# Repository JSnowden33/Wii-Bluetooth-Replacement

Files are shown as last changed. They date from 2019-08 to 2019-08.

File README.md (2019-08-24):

# Wii Bluetooth Replacement

<p align="center">
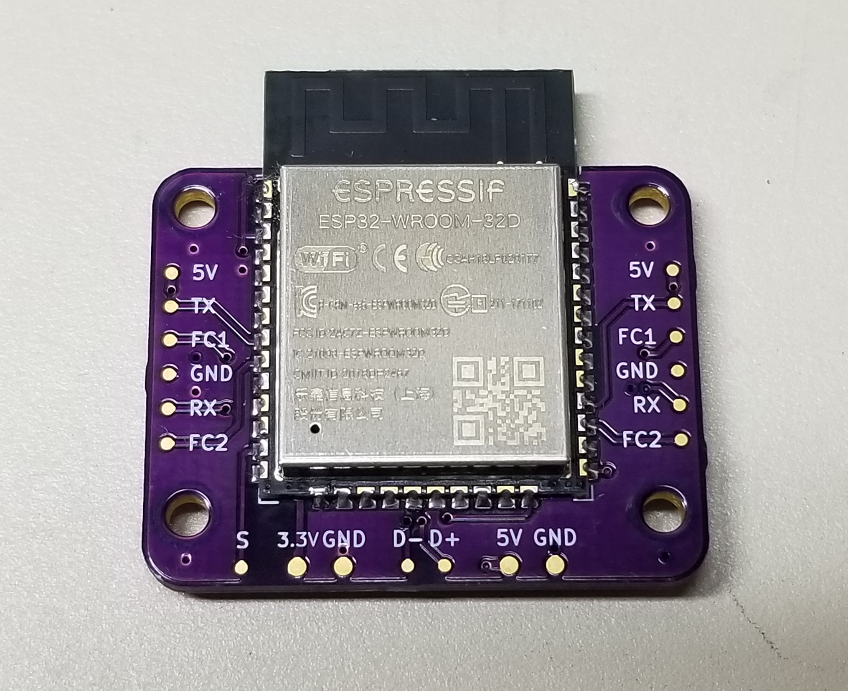
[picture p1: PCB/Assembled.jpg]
ESP32 Wii Bluetooth Replacement
  
</p>

This project is a full replacement for the Nintendo Wii's Bluetooth module. Emulation of the Bluetooth module is performed on the PIC32 based on [rnconrad's emulator](https://github.com/rnconrad/WiiBluetoothEmulator), while controller connectivity on the ESP32 is based on [btstack](https://github.com/bluekitchen/btstack).

The device interfaces with various wireless controllers and emulates up to 4 virtual Wii Remotes to communicate with the Wii. Virtual Wii Remotes can be configured to have a Nunchuk, Classic Controller, or neither. Currently supported controllers are Wii Remote, Wii U Pro Controller, Joy-Con, and Switch Pro Controller. Joy-Con can also be used through wired functionality.

The PCB for this design can be purchased [here](https://oshpark.com/shared_projects/co8uBM0Z).

## Usage

The board needs to be powered by 3.3V. The only connection needed to the Wii are the D+ and D- USB lines, which should be wired where the Bluetooth module normally sits. The 5V input is only used for Joy-Con charging and not needed to use the Joy-Con. The "S" pin is for the sync button, which can be a normally open tact switch connected to GND.

## Supported Features

- Permanent syncing: Press the sync button on the ESP32 along with the sync button on any controllers you want to pair. The ESP32 will pair and store each controller's information so reconnection works smoothly. Joy-Con can also be paired by docking them to the ESP32.

- Extension switching: Controllers that don't support physical extensions (Nunchuk and Classic Controller) can cycle through virtual extensions. Long-press Home to cycle through each one. Switch and Wii U Pro Controllers support sideways Wii Remote, Nunchuk, and Classic Controller. Dual Joy-Con support Nunchuk and Classic Controller. Single Joy-Con (R) supports only vertical Wii Remote and Joy-Con (L) supports only Nunchuk.

- IR pointer emulation: The Wii Remote IR pointer is emulated by gyro control (for Joy-Con, Switch Pro, and Wii Remote Plus) or by the right joystick for any controllers that have it. The cursor can be re-centered by pressing R (long-press Plus on Wii Remote). Gyro can be re-calibrated by long-pressing R (long-press Home on Wii Remote) and letting the controller be still for a few seconds.

## Planned Features

- New platform: A hardware revision is planned based on the PIC32MX470F512 and the TI CC2564 BT module. This will hopefully resolve some current hardware issues and improve data throughput with more processing speed.

- DPad to joystick mapping: The Wii Remote DPad will eventually be mapped to the left joystick whenever a controller has no virtual extension attached.

- More single Joy-Con functionality: Each single Joy-Con (L or R) will eventually be usable as its own Wii Remote. Single Joy-Con mode will be enabled by holding SL + SR for a few seconds after the Joy-Con is connected. Each will function as a sideways Wii Remote with full motion control and a gyro pointer which can be toggled by pressing the joystick.

- More wired Joy-Con functionality: Wired Joy-Con are not well tested and implementation is unfinished. They currently do not support virtual extensions or rumble. 

- Wii Motion Plus: Motion Plus emulation is mostly implemented but not tested. It should be functional on any controller with a gyroscope.

## Known Issues

This project is experimental and has plenty of bugs. Below is a list of some important issues that still need fixing.

- Wii Remote connectivity: Currently only newer Wii Remotes (TR versions) can auto-connect to the ESP32 by pressing any button on the controller. Older Wii Remotes must be synced every time. This is due to a hardware incompatibility with the ESP32 and fixing it will require moving away from the ESP32 platform.

- Joy-Con connectivity: Joy-Con are finnicky and sometimes won't auto-connect. Fixing this will also require moving away from the ESP32 platform (but this issue seems to exist on some other platforms too). Resetting the Joy-Con by pressing the black button on the side seems to help.

- Reconnecting a controller: The PIC32 currently doesn't handle reconnections very well and may become unusable in-game if you disconnect a controller and try to reconnect it. Power cycling may be necessary (pressing the reset button on the Wii doesn't reinitialize the Bluetooth module).

- Multiplayer use: Connecting more players beyond player 1 may not work well or at all depending on the software. Using two Joy-Con for the same player works fine.

- HD rumble: Joy-Con and Switch Pro Controllers do support rumble and it usually works fine, but sometimes it will stop working until the controller is reconnected. Needs to be looked into.

## Joy-Con Wiring

The Joy-Con wired connection follows the pin numbering provided [here](https://github.com/dekuNukem/Nintendo_Switch_Reverse_Engineering). On each Joy-Con, the pin names vs. pin numbers are as follows:

- 5V: Pin 4
- TX: Pin 5
- FC1: Pin 6
- GND: Pin 7
- RX: Pin 8
- FC2: Pin 10

If a Joy-Con rail connector is wired to the board, pins 1, 2, 3, and 7 on the rail should be grounded. Pin 9 should be left unconnected. Connecting 5V to pin 4 for charging is optional. Note that having 5V active on the rail at all times may be unsafe if the connection isn't tight. 
When assembling the board, components U1, U2, C3, C4, and C6 are used only for Joy-Con connectivity and can be left off if wired Joy-Con will not be used.

## Compiling and Programming

### PIC32

Compiling the PIC32 software requires MPLAB X IDE with XC32 installed. Simply open the .X folder under Software/PIC32 as an MPLAB project and compile. The compiled image can be flashed using a PICKit3 connected to the MCLR, PGD, and PGC pins on the underside of the board. The board will need to be powered externally and the PICKit3 will need to be connected to 3.3V and GND references.

### ESP32

Compiling the ESP32 software requires installing both esp-idf and btstack. On Windows 10, I use the Msys32 terminal for esp-idf. Btstack can be downloaded from [here](https://github.com/bluekitchen/btstack). The port/esp32/integrate_btstack.py script will install btstack to your system after esp-idf has been installed. The software can be flashed to the ESP32 using any USB-serial programmer that has the appropriate transistors on the DTS and RTS lines. Those transistors should be connected to the EN and BOOT pins on the underside of the board (RX and TX go to the communication pins of the serial port). Running "make flash" in the Msys32 terminal will compile and flash the software to your board. The first compilation will take a VERY long time.

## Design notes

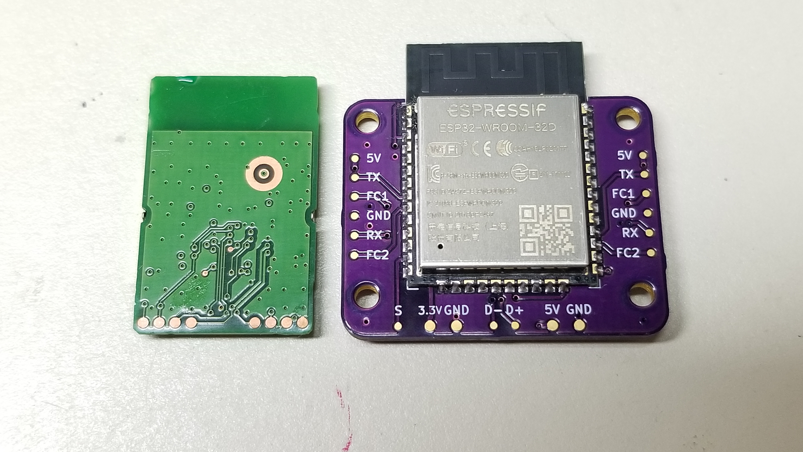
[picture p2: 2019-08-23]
PCB/Original vs Replacement.jpg

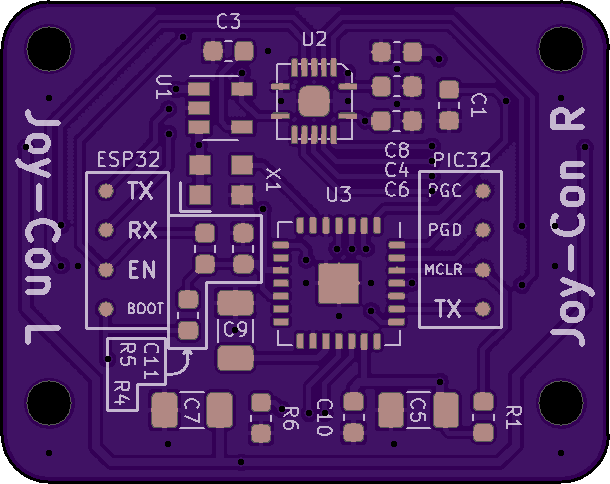
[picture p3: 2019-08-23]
PCB/Back.png

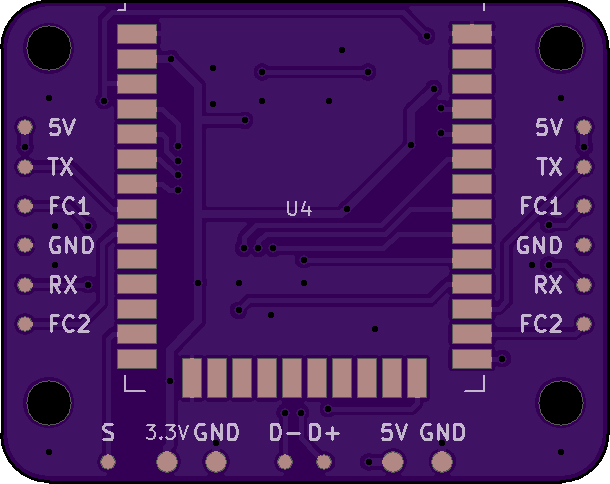
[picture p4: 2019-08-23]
PCB/Front.png

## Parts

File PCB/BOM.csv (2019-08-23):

Qty | Description | Value | Link
1 | SMD Capacitor 0603 | 1nF | Any - should be at least 6.3V tolerant
1 | SMD Capacitor 0603 | 22nF | Any - should be at least 6.3V tolerant
2 | SMD Capacitor 0603 | 0.1uF | Any - should be at least 6.3V tolerant
3 | SMD Capacitor 0603 | 1uF | Any - should be at least 6.3V tolerant
3 | SMD Capacitor 1206 | 10uF | Any - should be at least 6.3V tolerant
3 | SMD Resistor 0603 | 5kOhm | Any
1 | SMD Resistor 0603 | 12kOhm | Any
1 | 1.8V Linear Regulator | RT9193-18GB | https://www.digikey.com/product-detail/en/richtek-usa-inc/RT9193-18GB/1028-1016-1-ND/2470075
1 | Logic Level Translator | TXS0104ERGYR | https://www.digikey.com/product-detail/en/texas-instruments/TXS0104ERGYR/296-20698-1-ND/1143682
1 | PIC32 Microcontroller | PIC32MX270F256B-50I/ML | https://www.digikey.com/product-detail/en/microchip-technology/PIC32MX270F256B-50I-ML/PIC32MX270F256B-50I-ML-ND/4902624
1 | ESP32 Microcontroller | ESP32-WROOM-32D | https://www.digikey.com/product-detail/en/espressif-systems/ESP32-WROOM-32D/1904-1023-1-ND/9381732
1 | 8MHz Oscillator | ASEM1-8.000MHZ-LC-T | https://www.digikey.com/product-detail/en/abracon-llc/ASEM1-8.000MHZ-LC-T/535-9754-1-ND/1873288

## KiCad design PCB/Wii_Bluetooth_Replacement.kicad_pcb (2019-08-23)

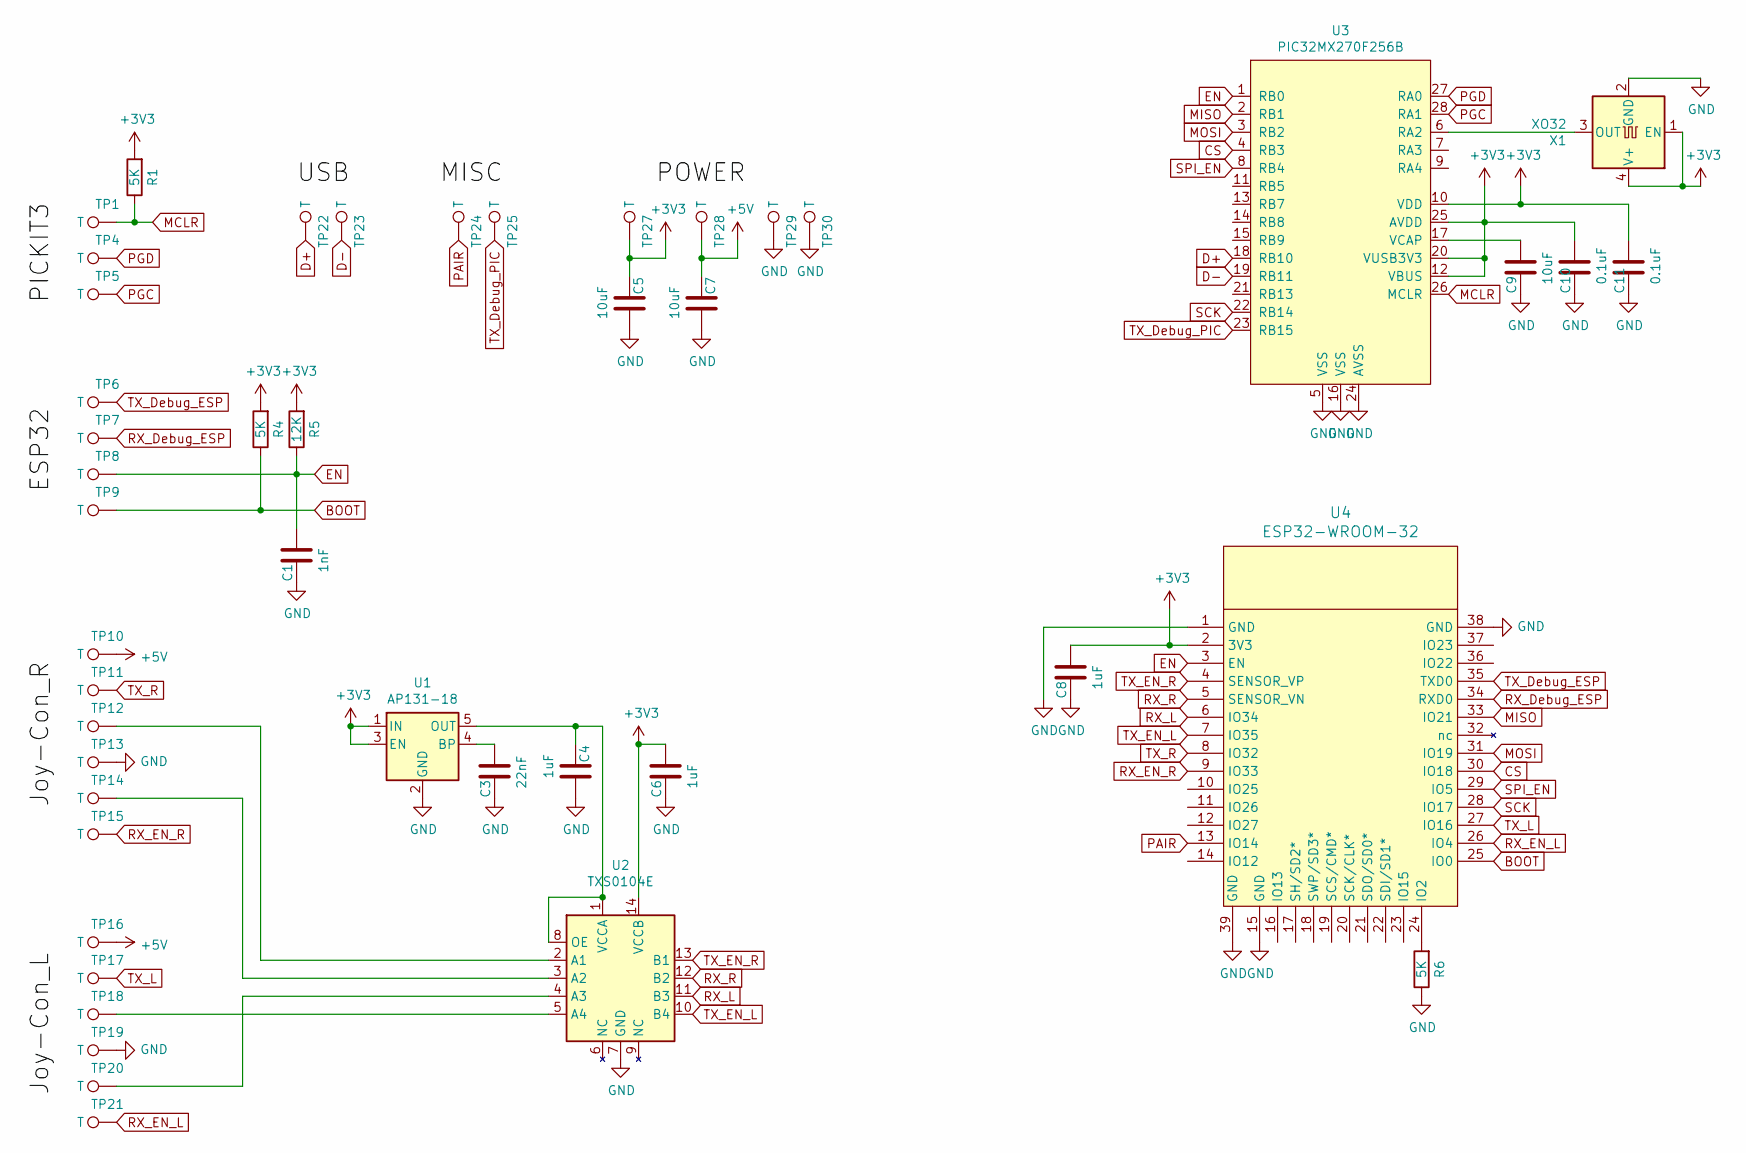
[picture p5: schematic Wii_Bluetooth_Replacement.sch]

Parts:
C1: 1nF; C_0603_1608Metric
C3: 22nF; C_0603_1608Metric
C4, C6, C8: 1uF; C_0603_1608Metric
C5, C7, C9: 10uF; C_1206_3216Metric
C10, C11: 0.1uF; C_0603_1608Metric
R1, R4, R6: 5K; R_0603_1608Metric
R5: 12K; R_0603_1608Metric
TP1, TP4, TP5, TP6, TP7, TP8, TP9, TP10, TP11, TP12, TP13, TP14, TP15, TP16, TP17, TP18, TP19, TP20, TP21, TP22, TP23, TP24, TP25: T; TestPoint_Pad_D0.7mm_NoSilk
TP27, TP28, TP29, TP30: T; TestPoint_Pad_D1.0mm_NoSilk
U1: AP131-18; SOT-23-5
U2: TXS0104E; VQFN-14_3.5x3.5mm_P0.5mm
U3: PIC32MX270F256B; QFN-28-1EP_6x6mm_P0.65mm_EP2.5x2.5mm
U4: ESP32-WROOM-32
X1: XO32; Oscillator_SMD_EuroQuartz_XO32-4Pin_3.2x2.5mm

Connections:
+3V3: C5.2, C6.1, C8.1, C10.1, C11.1, R1.2, R4.2, R5.2, TP27.1, U1.1 (IN), U1.3 (EN), U2.14 (VCCB), U3.10 (VDD), U3.12 (VBUS), U3.20 (VUSB3V3), U3.25 (AVDD), U4.2 (3V3), X1.1 (EN), X1.4 (V+)
+5V: C7.2, TP10.1, TP16.1, TP28.1
BOOT: R4.1, TP9.1, U4.25 (IO0)
CS: U3.4 (RB3), U4.30 (IO18)
D+: TP22.1, U3.18 (RB10)
D-: TP23.1, U3.19 (RB11)
EN: C1.1, R5.1, TP8.1, U3.1 (RB0), U4.3 (EN)
GND: C1.2, C3.2, C4.1, C5.1, C6.2, C7.1, C8.2, C9.2, C10.2, C11.2, R6.1, TP13.1, TP19.1, TP29.1, TP30.1, U1.2 (GND), U2.7 (GND), U2.15, U3.5 (VSS), U3.16 (VSS), U3.24 (AVSS), U3.29, U4.1 (GND), U4.15 (GND), U4.38 (GND), U4.39 (GND), X1.2 (GND)
MCLR: R1.1, TP1.1, U3.26 (MCLR)
MISO: U3.2 (RB1), U4.33 (IO21)
MOSI: U3.3 (RB2), U4.31 (IO19)
unnamed: C3.1, U1.4 (BP)
unnamed: C4.2, U1.5 (OUT), U2.1 (VCCA), U2.8 (OE)
unnamed: C9.1, U3.17 (VCAP)
unnamed: R6.2, U4.24 (IO2)
unnamed: TP12.1, U2.2 (A1)
unnamed: TP14.1, U2.3 (A2)
unnamed: TP18.1, U2.5 (A4)
unnamed: TP20.1, U2.4 (A3)
unnamed: U3.6 (RA2), X1.3 (OUT)
PAIR: TP24.1, U4.13 (IO14)
PGC: TP5.1, U3.28 (RA1)
PGD: TP4.1, U3.27 (RA0)
RX_Debug_ESP: TP7.1, U4.34 (RXD0)
RX_EN_L: TP21.1, U4.26 (IO4)
RX_EN_R: TP15.1, U4.9 (IO33)
RX_L: U2.11 (B3), U4.6 (IO34)
RX_R: U2.12 (B2), U4.5 (SENSOR_VN)
SCK: U3.22 (RB14), U4.28 (IO17)
SPI_EN: U3.8 (RB4), U4.29 (IO5)
TX_Debug_ESP: TP6.1, U4.35 (TXD0)
TX_Debug_PIC: TP25.1, U3.23 (RB15)
TX_EN_L: U2.10 (B4), U4.7 (IO35)
TX_EN_R: U2.13 (B1), U4.4 (SENSOR_VP)
TX_L: TP17.1, U4.27 (IO16)
TX_R: TP11.1, U4.8 (IO32)

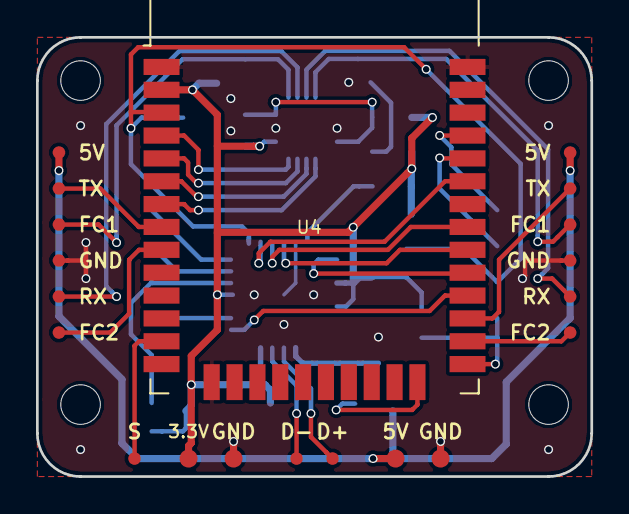
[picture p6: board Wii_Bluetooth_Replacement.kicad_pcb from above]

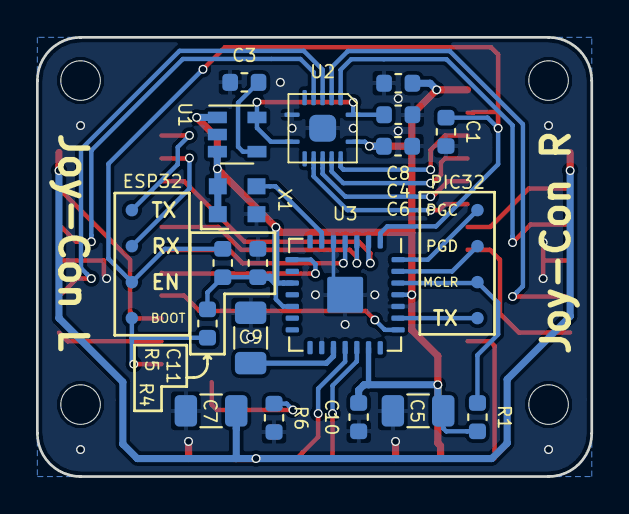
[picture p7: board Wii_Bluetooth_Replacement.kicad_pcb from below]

Board: 2 copper layers, 30.8 x 24.4 mm, 46 parts (26 on the bottom side), 36 nets.

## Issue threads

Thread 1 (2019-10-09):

Wii Remote connectivity on older Wii Remotes

gustavodinis, 2019-10-09:
Hello,
With regard to this known issue:
Wii Remote connectivity: Currently only newer Wii Remotes (TR versions) can auto-connect to the ESP32 by pressing any button on the controller. Older Wii Remotes must be synced every time. This is due to a hardware incompatibility with the ESP32 and fixing it will require moving away from the ESP32 platform.

Can you please provide any insights of what the problem is? I'm trying to figure out a solution. I don't have a Bluetooth sniffer but I'm assuming that is some issue with the BTstack of ESP32.

Thank you in advance and apologies for opening an issue (only way for me to get in touch with your work)

JSnowden33, 2019-10-09:
Hi,

There isn't much info on the issue except what is mentioned here: https://groups.google.com/forum/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

The original Wiimote can be synced to the ESP32, but reconnection fails. The Wiimote basically does not see the ESP32's request for role switch during reconnection. It seems as if the Wiimote does not see the commands exactly as they are sent from BTstack, so it may be some hardware issue in the physical link between the ESP32 and the Wiimote. It's hard to say how this could be debugged without a Bluetooth sniffer.

nathanRamaNoodles, 2020-01-09:
If we get a Bluetooth sniffer won't the data still be encrypted since its Bluetooth Classic?  I was reading an [issue in Ubertooth's repo](https://github.com/greatscottgadgets/ubertooth/issues/302#issuecomment-373445950) and their sniffer can't decrypt the Wii's Bluetooth packets.

Is there another sniffer that would work to sniff BT Classic?

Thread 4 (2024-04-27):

Reverse

pknessness, 2024-04-27:
Are there resources I could use to attempt to do this in the opposite way? I would like to have an ESP32 pretend to be a wii remote and connect to my wii.

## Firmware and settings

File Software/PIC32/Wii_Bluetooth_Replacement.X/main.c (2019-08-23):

#include <stdint.h>
#include <stdbool.h>
#include <stdlib.h>
#include "usb.h"
#include "hci.h"
#include <xc.h>
#include <string.h>
#include "usb_config.h"
#include "usb_ch9.h"
#include "usb_hid.h"
#include "uart.h"
#include "delay.h"
#include "wiimote.h"

// DEVCFG3
#pragma config PMDL1WAY = OFF           // Peripheral Module Disable Configuration (Allow only one reconfiguration)
#pragma config IOL1WAY = OFF            // Peripheral Pin Select Configuration (Allow only one reconfiguration)
#pragma config FUSBIDIO = ON            // USB USID Selection (Controlled by the USB Module)
#pragma config FVBUSONIO = OFF          // USB VBUS ON Selection (Controlled by software)

// DEVCFG2
#pragma config FPLLIDIV = DIV_2         // PLL Input Divider (2x Divider)
#pragma config FPLLMUL = MUL_15         // PLL Multiplier (15x Multiplier)
#pragma config UPLLIDIV = DIV_2         // USB PLL Input Divider (2x Divider)
#pragma config UPLLEN = ON              // USB PLL Enable (Enabled)
//#pragma config FPLLODIV = DIV_2         // System PLL Output Clock Divider (PLL Divide by 2) (30 MHz)
#pragma config FPLLODIV = DIV_1         // System PLL Output Clock Divider (PLL Divide by 1) (60 MHz, overclocked)

// DEVCFG1
#pragma config FNOSC = PRIPLL           // Oscillator Selection Bits (Primary Osc w/PLL (XT+,HS+,EC+PLL))
#pragma config FSOSCEN = OFF            // Secondary Oscillator Enable (Disabled)
#pragma config IESO = OFF               // Internal/External Switch Over (Disabled)
#pragma config POSCMOD = HS             // Primary Oscillator Configuration (HS osc mode)
#pragma config OSCIOFNC = OFF           // CLKO Output Signal Active on the OSCO Pin (Disabled)
#pragma config FPBDIV = DIV_4           // Peripheral Clock Divisor (Pb_Clk is Sys_Clk/4)
#pragma config FCKSM = CSDCMD           // Clock Switching and Monitor Selection (Clock Switch Disable, FSCM Disabled)
#pragma config WDTPS = PS1              // Watchdog Timer Postscaler (1:1)
#pragma config WINDIS = OFF             // Watchdog Timer Window Enable (Watchdog Timer is in Non-Window Mode)
#pragma config FWDTEN = OFF             // Watchdog Timer Enable (WDT Disabled (SWDTEN Bit Controls))
#pragma config FWDTWINSZ = WINSZ_25     // Watchdog Timer Window Size (Window Size is 25%)

// DEVCFG0
#pragma config JTAGEN = OFF             // JTAG Enable (JTAG Port Enabled)
#pragma config ICESEL = ICS_PGx1        // ICE/ICD Comm Channel Select (Communicate on PGEC1/PGED1)
#pragma config PWP = OFF                // Program Flash Write Protect (Disable)
#pragma config BWP = OFF                // Boot Flash Write Protect bit (Protection Disabled)
#pragma config CP = OFF                 // Code Protect (Protection Disabled)

static int32_t hci_len = 0;
static uint32_t hci_reset_timer = 0;

static uint32_t _excep_code;
static uint32_t _excep_addr;
// This function overrides the normal weak generic handler
void _general_exception_handler(void) {
	asm volatile("mfc0 %0,$13" : "=r" (_excep_code));
	asm volatile("mfc0 %0,$14" : "=r" (_excep_addr));
	_excep_code = (_excep_code & 0x0000007C) >> 2;    

	uart_transmit("Exception value/address:", 1);
	uart_transmit_val(_excep_code, 8, 1);
	uart_transmit_val(_excep_addr, 8, 1);

	while (1);
}

void __attribute__((vector(_TIMER_3_VECTOR), interrupt(), nomips16)) _T3Interrupt() {
	main_timer++;	// Count ms
	IFS0bits.T3IF = 0;
}

int main(void) {
	TRISBbits.TRISB0 = 0;	// ESP32 EN
	TRISBbits.TRISB1 = 1;	// SDI
	TRISBbits.TRISB2 = 0;   // SDO
	TRISBbits.TRISB3 = 0;   // CS
	TRISBbits.TRISB4 = 1;   // SPI_EN
	TRISBbits.TRISB14 = 0;  // SCK
	TRISBbits.TRISB15 = 0;  // TX
	
	LATBbits.LATB0 = 0;

	// Set all pins as digital
	ANSELA = 0;
	ANSELB = 0;

	// Allow multi-vector interrupts for USB
	INTCONbits.MVEC = 1;
	IPC7bits.USBIP = 4;
	__asm volatile("ei");

	t2_count_ms();
	uart_configure(115200);
	spi_master_init(2000000, 1);
	uart_transmit("UART init", 1);

	if (RCONbits.SWR) uart_transmit("RST - software", 1);
	if (RCONbits.WDTO) uart_transmit("RST - watchdog", 1);
	if (RCONbits.SLEEP) uart_transmit("RST - wakeup", 1);
	if (RCONbits.IDLE) uart_transmit("RST - was idle", 1);
	if (RCONbits.BOR) uart_transmit("RST - brown-out", 1);
	if (RCONbits.POR) uart_transmit("RST - power-on", 1);
	RCON = 0;

	usb_init();
	
	LATBbits.LATB0 = 1;
	TRISBbits.TRISB0 = 1;

	while (1) {
		if (usb_is_configured()) {
			if (!usb_in_endpoint_busy(1)) {
				int32_t len = hci_get_event(usb_get_in_buffer(1));
				if (len > 0) usb_send_in_buffer(1, len);
			}
			if (!usb_in_endpoint_busy(2)) {
				int32_t len = hci_get_data(usb_get_in_buffer(2));
				if (len > 0) usb_send_in_buffer(2, len);
			}
		}
		
		update_wiimotes();
		
		// Handle ESP32 reset
		/*
		if (hci_reset_status) {
			hci_reset_timer = main_timer;
			hci_reset_status = 0;
			TRISBbits.TRISB0 = 0;
			LATBbits.LATB0 = 0;
		}
		if ((main_timer - hci_reset_timer >= 50) && !PORTBbits.RB0) {
			LATBbits.LATB0 = 1;
			TRISBbits.TRISB0 = 1;
		}
		*/
	}
	return 0;
}

/* Callbacks. These function names are set in usb_config.h. */

void app_set_configuration_callback(uint8_t configuration) {

}

uint16_t app_get_device_status_callback() {
	return 0x0000;
}

void app_endpoint_halt_callback(uint8_t endpoint, bool halted) {

}

int8_t app_set_interface_callback(uint8_t interface, uint8_t alt_setting) {
	return 0;
}

int8_t app_get_interface_callback(uint8_t interface) {
	return 0;
}

void app_out_transaction_callback(uint8_t endpoint) {
	// Received data from the bulk endpoint
	uint8_t len;
	uint8_t * buf;
	len = usb_get_out_buffer(2, (const unsigned char **)&buf);

	hci_recv_data(buf, len);
	usb_arm_out_endpoint(2);
}

void app_in_transaction_complete_callback(uint8_t endpoint) {

}

int8_t ep0_cb(bool data_ok, void * context) {
	if (data_ok) {
		hci_recv_command(hci_len);
		return 0;
	} else return -1;
}

int8_t app_unknown_setup_request_callback(const struct setup_packet *setup) {
	if (setup->REQUEST.type == 1) {	// Class request (HCI command)? 
		hci_len = setup->wLength;
		usb_start_receive_ep0_data_stage(hci_get_cmd_buffer(), setup->wLength, (usb_ep0_data_stage_callback)ep0_cb, NULL);
		return 0;
	} else return -1;
}

int16_t app_unknown_get_descriptor_callback(const struct setup_packet *pkt, const void **descriptor) {
	return 0;
}

//void app_start_of_frame_callback(void)
//{
//
//}
//
//void app_usb_reset_callback(void)
//{
//
//}

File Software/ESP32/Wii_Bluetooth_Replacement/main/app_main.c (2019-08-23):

#define BTSTACK_FILE__ "app_main.c"

#include <inttypes.h>
#include <stdio.h>
#include "btstack_config.h"
#include "btstack.h"
#include "freertos/FreeRTOS.h"
#include "freertos/task.h"
#include "driver/gpio.h"
#include "driver/uart.h"
#include "rom/ets_sys.h"
#include "esp_system.h"
#include "driver/timer.h"
#include "connect.h"
#include "gamepad.h"
#include "hid_controller.h"
#include "pair.h"
#include "spi.h"
#include "uart_controller.h"
#include "timer.h"
#include "wiimote.h"

#define PAIR_PIN GPIO_NUM_14

static btstack_timer_source_t app_loop;
uint64_t app_timer;	// App time running in ms
uint32_t prev_time = 0;
uint8_t spi_en = 0;

static btstack_packet_callback_registration_t hci_event_callback_registration;
static btstack_packet_callback_registration_t l2cap_event_callback_registration;
static btstack_packet_callback_registration_t gap_event_callback_registration;
 
static void hci_event_handler (uint8_t packet_type, uint16_t channel, uint8_t *packet, uint16_t size);
static void hci_event_handler(uint8_t packet_type, uint16_t channel, uint8_t *packet, uint16_t size)
{
    uint8_t event;
	uint8_t i;

    if (packet_type == HCI_EVENT_PACKET) {
		event = hci_event_packet_get_type(packet);
		switch (event) {            
			case BTSTACK_EVENT_STATE:
				if (btstack_event_state_get_state(packet) == HCI_STATE_WORKING) {
					gap_local_bd_addr(host_mac_addr);	// Get host MAC address
					for (i = 0; i < 6; i++) host_mac_addr_rev[i] = host_mac_addr[5 - i];
					memcpy(host_mac_string, host_mac_addr_rev, 6);
					host_mac_string[6] = 0;
					l2cap_register_service(l2cap_event_handler, HID_CONTROL_PSM, 64, LEVEL_2);
					l2cap_register_service(l2cap_event_handler, HID_INTERRUPT_PSM, 64, LEVEL_2);
				}
				break;
			default:
				break;
		}
    }
}

void app_loop_handler(btstack_timer_source_t *ts) {
    UNUSED(ts);
	timer_get_counter_value(TIMER_GROUP_1, TIMER_1, &app_timer);
	app_timer = app_timer / 1000;	// Convert us to ms

	if (!gpio_get_level(PAIR_PIN) && app_timer >= 1000) start_scan();
	pair_timeout_check();

	// Check device inquiry results
	if (ready_to_pair()) {
		enum HID_DEVICE controller_type;
		uint8_t * controller_addr;
		controller_addr = get_next_discovered_controller_addr(&controller_type);
		hid_controller_t * new_controller = register_controller(controller_type, controller_addr);
		if (new_controller) begin_pair(new_controller);
		else {
			printf("Unable to pair - too many other controllers connected or already connected\n");
			end_pair(NULL);
		}
	}

	uart_joycon_handle(&joycon_right);
	uart_joycon_handle(&joycon_left);

	controller_handle(1);
	controller_handle(2);
	controller_handle(3);
	controller_handle(4);
	controller_handle(5);
	controller_handle(6);
	controller_handle(7);
	controller_handle(8);

	gamepad_handle(1);
	gamepad_handle(2);
	gamepad_handle(3);
	gamepad_handle(4);

	if ((app_timer >= 1500) && !spi_en) {
		spi_en = 1;
		gpio_set_level(SPI_EN, 1);	// Accept SPI transfers
	}
	
	if (app_timer - prev_time >= 15) {
		wiimote_spi_receive();
		wiimote_spi_send(1);
		wiimote_spi_send(2);
		wiimote_spi_send(3);
		wiimote_spi_send(4);
		prev_time = app_timer;
	}

	// Re-register timer
	btstack_run_loop_set_timer(&app_loop, APP_LOOP_PERIOD_MS);
	btstack_run_loop_add_timer(&app_loop);
} 

int btstack_main(int argc, const char * argv[]);
int btstack_main(int argc, const char * argv[]) {
    (void)argc;
    (void)argv;

	spi_slave_init(GPIO_NUM_19, GPIO_NUM_21, GPIO_NUM_17, GPIO_NUM_18);
	uart_init();

	init_controllers();
	init_gamepads();
	init_wiimotes();
	
	gpio_set_direction(PAIR_PIN, GPIO_MODE_INPUT);
	gpio_set_pull_mode(PAIR_PIN, GPIO_PULLUP_ONLY);
	gpio_set_direction(SPI_EN, GPIO_MODE_OUTPUT);
	gpio_set_level(SPI_EN, 0);

    l2cap_init();
	
	// Name must contain "Nintendo" to keep Switch controllers connected? But "Nintendo Switch" causes button latency
	gap_set_local_name("Nintendo");
	
	hci_set_inquiry_mode(INQUIRY_MODE_RSSI_AND_EIR);
	hci_set_master_slave_policy(0);	// Always begin connection as master

    hci_event_callback_registration.callback = &hci_event_handler;
    hci_add_event_handler(&hci_event_callback_registration);
	l2cap_event_callback_registration.callback = &l2cap_event_handler;
    hci_add_event_handler(&l2cap_event_callback_registration);
	gap_event_callback_registration.callback = &gap_event_handler;
    hci_add_event_handler(&gap_event_callback_registration);

    setbuf(stdout, NULL);
	//if (!gpio_get_level(PAIR_PIN)) hci_dump_open(NULL, HCI_DUMP_STDOUT);	// Dump HCI and ACL logs if button is held
    hci_power_control(HCI_POWER_ON);

	timer_config_t config = {
		.alarm_en = false,
		.counter_en = false,
		.counter_dir = TIMER_COUNT_UP,
		.divider = 80	// 1 us per tick - ticks per second is (80 MHz / divider)
    };
    
	app_timer = 0;
    timer_init(TIMER_GROUP_1, TIMER_1, &config);
    timer_set_counter_value(TIMER_GROUP_1, TIMER_1, 0);
    timer_start(TIMER_GROUP_1, TIMER_1);
	
	app_loop.process = &app_loop_handler;
    btstack_run_loop_set_timer(&app_loop, APP_LOOP_PERIOD_MS);
    btstack_run_loop_add_timer(&app_loop);
	
    return 0;
}

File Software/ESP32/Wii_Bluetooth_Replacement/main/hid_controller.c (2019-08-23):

#include <inttypes.h>
#include <stdio.h>
#include "btstack.h"
#include "gamepad.h"
#include "hid_command.h"
#include "hid_controller.h"
#include "pair.h"
#include "uart_controller.h"
#include "timer.h"
#include "driver/timer.h"

hid_controller_t controllers[8];

const uint8_t rumble_off_data[8] = { 0x00, 0x01, 0x40, 0x40, 0x00, 0x01, 0x40, 0x40 };
const uint8_t rumble_on_data[8] = { 0x00, 0x00, 0x4B, 0x60, 0x00, 0x00, 0x4B, 0x60 };	// Medium-force rumble using low-band only (about 200 Hz)

const uint8_t ext_id_nunchuk[6] = { 0x00, 0x00, 0xA4, 0x20, 0x00, 0x00 };
const uint8_t ext_id_classic[6] = { 0x00, 0x00, 0xA4, 0x20, 0x01, 0x01 };
const uint8_t ext_id_classic_pro[6] = { 0x01, 0x00, 0xA4, 0x20, 0x01, 0x01 };
const uint8_t ext_id_wiiu_pro[6] = { 0x00, 0x00, 0xA4, 0x20, 0x01, 0x20 };

const uint8_t ext_id_wmp_inactive[6] = { 0x00, 0x00, 0xA6, 0x20, 0x00, 0x05 };
const uint8_t ext_id_wmp_active[6] = { 0x00, 0x00, 0xA4, 0x20, 0x04, 0x05 };
const uint8_t ext_id_wmp_nunchuk[6] = { 0x00, 0x00, 0xA4, 0x20, 0x05, 0x05 };
const uint8_t ext_id_wmp_classic[6] = { 0x00, 0x00, 0xA4, 0x20, 0x07, 0x05 };

void hid_queue_command(hid_controller_t * controller, const hid_command_t * command, uint8_t * arg, command_response_cb response_cb, uint8_t response_required) {
	hid_command_t * cur_command = &controller->command_buffer[(controller->command_buffer_pos + controller->command_queue_num) % 32];
	memcpy(cur_command, command, sizeof(hid_command_t));
	cur_command->response_required = response_required;
	cur_command->response_cb = response_cb;	// Register callback for response

	// Add command arguments if provided
	if (arg) {
		memcpy(cur_command->cmd + cur_command->arg_offset, arg, cur_command->arg_len);
		if ((cur_command->arg_offset + cur_command->arg_len) > cur_command->len) cur_command->len += (cur_command->arg_offset + cur_command->arg_len - cur_command->len);
	}

	controller->command_queue_num++;
	//printf("%d reports queued\n", controller->command_queue_num);
}

uint8_t hid_send_next_command(hid_controller_t * controller) {
	if (controller->command_queue_num) {
		hid_command_t * command = &controller->command_buffer[controller->command_buffer_pos];
		switch (controller->type) {
			case CNT_JOYCON_R:
			case CNT_JOYCON_L:
			case CNT_PROCON:
				if (command->cmd[1] == 0x01 || command->cmd[1] == 0x10) {	// Check if subcommand or rumble command
					command->cmd[2] = controller->command_packet_count;
					controller->command_packet_count = (controller->command_packet_count + 1) % 0x10;
					if (controller->rumble) memcpy(command->cmd + 3, rumble_on_data, 8);
					else memcpy(command->cmd + 3, rumble_off_data, 8);
				}
				break;
			case CNT_WIIMOTE:
			case CNT_WIIU_PRO:
				if (controller->rumble) command->cmd[2] |= 0x01;	// Turn rumble on
				else command->cmd[2] &= 0xFE;	// Turn rumble off
				break;
			default:
				break;
		}

		printf("%llu - ", app_timer);
		printf_hexdump(command->cmd, command->len);
		
		controller->command_send_event_queued = 1;
		controller->command_queue_num--;
		l2cap_request_can_send_now_event(controller->l2cap_interrupt_cid);
		return 1;
	}
	return 0;
}

void hid_get_response(hid_controller_t * controller, uint8_t * response, uint8_t response_size) {
	if ((response[1] & 0x30) == 0x30) {
		memset(controller->status_response, 0, 64);
		memcpy(controller->status_response, response, response_size);
		controller->status_response_len = response_size;
		controller->status_response_received = 1;
		gamepad_get_angles_from_controller(controller);	// Angle calculations performed here to avoid latency
	} else {
		memset(controller->command_response, 0, 64);
		memcpy(controller->command_response, response, response_size);
		controller->command_response_len = response_size;
		controller->command_response_received = 1;
		//printf("Command response received\n");
		printf("%llu - ", app_timer);
		printf_hexdump(controller->command_response, controller->command_response_len);

		// Check if new response belongs to previous command
		if (hid_response_matches_command(controller, &controller->command_buffer[(controller->command_buffer_pos - 1) % 32]))
			controller->command_response_verified = 1;
	}

	switch (controller->type) {
		case CNT_JOYCON_R:
		case CNT_JOYCON_L:
		case CNT_PROCON:
			break;
		case CNT_WIIMOTE:
			// Check WMP extension status
			if ((response[1] == 0x37) && (response[22] != 0xFF) && (controller->wmp_type == WMP_SUPPORTED) && controller->wmp_active) {	// If byte 22 is 0xFF then WMP is not sending data yet
				if ((response[21] & 0x01) && (controller->extension_type == EXT_NONE))	// Extension plugged in
					controller_detect_extension(controller);	
				if (!(response[21] & 0x01) && (controller->extension_type != EXT_NONE))	// Extension unplugged
					controller_detect_extension(controller);
			}
			// Check general extension status (report mode must always be updated here)
			else if (response[1] == 0x20) {
				if (controller->wmp_type == WMP_NOT_SUPPORTED) controller_detect_extension(controller);
				else if (controller->wmp_type == WMP_SUPPORTED) hid_queue_command(controller, &cmd_wiimote_report_mode_acc_ir10_ext6, NULL, NULL, 1);
				else hid_queue_command(controller, &cmd_wiimote_report_mode_acc_ir12, NULL, NULL, 1);
			}
			break;
		default:
			break;
	}
}

uint8_t hid_response_matches_command(hid_controller_t * controller, hid_command_t * command) {
	switch (controller->type) {
		case CNT_JOYCON_R:
		case CNT_JOYCON_L:
		case CNT_PROCON:
			switch (command->name) {
				// SPI flash read commands
				case READ_CAL_IMU_FACTORY:
				case READ_CAL_JOY_L_FACTORY:
				case READ_CAL_JOY_R_FACTORY:
				case READ_CAL_IMU_USER:
				case READ_CAL_JOY_L_USER:
				case READ_CAL_JOY_R_USER:
					if (!memcmp(controller->command_response + 15, command->cmd + 11, 6)) return 1;
					break;
				// Standard subcommands
				default:
					if (!memcmp(controller->command_response + 15, command->cmd + 11, 1)) return 1;
					break;
			}
			break;
		case CNT_WIIMOTE:
		case CNT_WIIU_PRO:
			switch (command->name) {
				// Status command
				case GET_STATUS:
					if (controller->command_response[1] == 0x20) return 1;
					break;
				// I2C flash read commands
				case READ_EXTENSION_ID:
				case READ_WMP_ID:
				case READ_CAL_EXTENSION:
				case READ_CAL_WMP:
				case READ_CAL_ACCEL:
					if ((controller->command_response[1] == 0x21) && !memcmp(controller->command_response + 5, command->cmd + 4, 2)) return 1;
					break;
				// Standard command response
				default:
					if ((controller->command_response[1] == 0x22) && (controller->command_response[4] == command->cmd[1])) return 1;
					break;
			}
			break;
		default:
			break;
	}
	return 0;
}
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

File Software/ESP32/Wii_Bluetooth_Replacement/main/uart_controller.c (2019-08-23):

#include <inttypes.h>
#include <stdio.h>
#include "btstack_config.h"
#include "btstack.h"
#include "freertos/FreeRTOS.h"
#include "freertos/task.h"
#include "soc/timer_group_struct.h"
#include "soc/timer_group_reg.h"
#include "driver/gpio.h"
#include "driver/uart.h"
#include "rom/ets_sys.h"
#include "esp_system.h"
#include "gamepad.h"
#include "timer.h"
#include "uart_controller.h"
#include "pair.h"

// Subcommand format:
// Header is constant (19 01 03 38 00 92 00 31)
// Bytes 10-11 change rapidly - some kind of timer?
// Byte 12 is "01" for subcommand
// Byte 13 is packet counter (0 - F)
// Bytes 14-21 are rumble (same as Bluetooth subcommand)
// Byte 22 is subcommand ID
// Following bytes are standard subcommand arguments

uint8_t uart_handshake_commands[15][64] = {
    { 16,   0xA1, 0xA2, 0xA3, 0xA4, 0x19, 0x01, 0x03, 0x07, 0x00, 0xA5, 0x02, 0x01,	0x7E, 0x00, 0x00, 0x00 },	// Handshake 1
    { 12,   0x19, 0x01, 0x03, 0x07, 0x00, 0x91, 0x01, 0x00, 0x00, 0x00, 0x00, 0x24 },	// Get MAC address
    { 16,   0x19, 0x01, 0x03, 0x0B, 0x00, 0x91, 0x02, 0x04, 0x00, 0x00, 0x38, 0xE6, 0x14, 0x00, 0x00, 0x00 },	// Handshake 2
    { 20,   0x19, 0x01, 0x03, 0x0F, 0x00, 0x91, 0x20, 0x08, 0x00, 0x00, 0xBD, 0xB1, 0xC0, 0xC6, 0x2D, 0x00, 0x00, 0x00, 0x00, 0x00 },	// Switch baud rate
    { 12,   0x19, 0x01, 0x03, 0x07, 0x00, 0x91, 0x11, 0x00, 0x00, 0x00, 0x00, 0x0E }, 	// Pair 1
    { 12,   0x19, 0x01, 0x03, 0x07, 0x00, 0x91, 0x10, 0x00, 0x00, 0x00, 0x00, 0x3D }, 	// Pair 2
    { 16,   0x19, 0x01, 0x03, 0x0B, 0x00, 0x91, 0x12, 0x04, 0x00, 0x00, 0x12, 0xA6, 0x0F, 0x00, 0x00, 0x00 },	// Pair 3
	{ 61,   0x19, 0x01, 0x03, 0x38, 0x00, 0x92, 0x00, 0x31, 0x00, 0x00, 0x00, 0x00,   	// Read IMU calibration
      0x01, 0x04, 0x00, 0x01, 0x40, 0x40, 0x00, 0x01, 0x40, 0x40, 0x10, 0x20, 
      0x60, 0x00, 0x00, 0x18, 0x00, 0x00, 0x00, 0x00, 0x00, 0x00, 0x00, 0x00, 
      0x00, 0x00, 0x00, 0x00, 0x00, 0x00, 0x00, 0x00, 0x00, 0x00, 0x00, 0x00, 
      0x00, 0x00, 0x00, 0x00, 0x00, 0x00, 0x00, 0x00, 0x00, 0x00, 0x00, 0x00, 
      0x00 },
	{ 61,   0x19, 0x01, 0x03, 0x38, 0x00, 0x92, 0x00, 0x31, 0x00, 0x00, 0x00, 0x00,   	// Read right joystick calibration
      0x01, 0x00, 0x00, 0x01, 0x40, 0x40, 0x00, 0x01, 0x40, 0x40, 0x10, 0x3D, 
      0x60, 0x00, 0x00, 0x09, 0x00, 0x00, 0x00, 0x00, 0x00, 0x00, 0x00, 0x00, 
      0x00, 0x00, 0x00, 0x00, 0x00, 0x00, 0x00, 0x00, 0x00, 0x00, 0x00, 0x00, 
      0x00, 0x00, 0x00, 0x00, 0x00, 0x00, 0x00, 0x00, 0x00, 0x00, 0x00, 0x00, 
      0x00 },
	{ 61,   0x19, 0x01, 0x03, 0x38, 0x00, 0x92, 0x00, 0x31, 0x00, 0x00, 0x00, 0x00,   	// Read left joystick calibration
      0x01, 0x00, 0x00, 0x01, 0x40, 0x40, 0x00, 0x01, 0x40, 0x40, 0x10, 0x46, 
      0x60, 0x00, 0x00, 0x09, 0x00, 0x00, 0x00, 0x00, 0x00, 0x00, 0x00, 0x00, 
      0x00, 0x00, 0x00, 0x00, 0x00, 0x00, 0x00, 0x00, 0x00, 0x00, 0x00, 0x00, 
      0x00, 0x00, 0x00, 0x00, 0x00, 0x00, 0x00, 0x00, 0x00, 0x00, 0x00, 0x00, 
      0x00 },
	{ 61,   0x19, 0x01, 0x03, 0x38, 0x00, 0x92, 0x00, 0x31, 0x00, 0x00, 0x00, 0x00,   	// Begin pairing
      0x01, 0x00, 0x00, 0x01, 0x40, 0x40, 0x00, 0x01, 0x40, 0x40, 0x01, 0x01, 
      0x00, 0x00, 0x00, 0x00, 0x00, 0x00, 0x00, 0x00, 0x00, 0x00, 0x00, 0x00, 
      0x00, 0x00, 0x00, 0x00, 0x00, 0x00, 0x00, 0x00, 0x00, 0x00, 0x00, 0x00, 
      0x00, 0x00, 0x00, 0x00, 0x00, 0x00, 0x00, 0x00, 0x00, 0x00, 0x00, 0x00, 
      0x00 },
	{ 61,   0x19, 0x01, 0x03, 0x38, 0x00, 0x92, 0x00, 0x31, 0x00, 0x00, 0x00, 0x00,   	// Get pair key
      0x01, 0x00, 0x00, 0x01, 0x40, 0x40, 0x00, 0x01, 0x40, 0x40, 0x01, 0x02, 
      0x00, 0x00, 0x00, 0x00, 0x00, 0x00, 0x00, 0x00, 0x00, 0x00, 0x00, 0x00, 
      0x00, 0x00, 0x00, 0x00, 0x00, 0x00, 0x00, 0x00, 0x00, 0x00, 0x00, 0x00, 
      0x00, 0x00, 0x00, 0x00, 0x00, 0x00, 0x00, 0x00, 0x00, 0x00, 0x00, 0x00, 
      0x00 },
	{ 61,   0x19, 0x01, 0x03, 0x38, 0x00, 0x92, 0x00, 0x31, 0x00, 0x00, 0x00, 0x00,   	// Save pair key
      0x01, 0x00, 0x00, 0x01, 0x40, 0x40, 0x00, 0x01, 0x40, 0x40, 0x01, 0x03, 
      0x00, 0x00, 0x00, 0x00, 0x00, 0x00, 0x00, 0x00, 0x00, 0x00, 0x00, 0x00, 
      0x00, 0x00, 0x00, 0x00, 0x00, 0x00, 0x00, 0x00, 0x00, 0x00, 0x00, 0x00, 
      0x00, 0x00, 0x00, 0x00, 0x00, 0x00, 0x00, 0x00, 0x00, 0x00, 0x00, 0x00, 
      0x00 },
	{ 61,   0x19, 0x01, 0x03, 0x38, 0x00, 0x92, 0x00, 0x31, 0x00, 0x00, 0x00, 0x00,   	// Enable IMU
      0x01, 0x00, 0x00, 0x01, 0x40, 0x40, 0x00, 0x01, 0x40, 0x40, 0x40, 0x01, 
      0x00, 0x00, 0x00, 0x00, 0x00, 0x00, 0x00, 0x00, 0x00, 0x00, 0x00, 0x00, 
      0x00, 0x00, 0x00, 0x00, 0x00, 0x00, 0x00, 0x00, 0x00, 0x00, 0x00, 0x00, 
      0x00, 0x00, 0x00, 0x00, 0x00, 0x00, 0x00, 0x00, 0x00, 0x00, 0x00, 0x00, 
      0x00 },
    { 13,   0x19, 0x01, 0x03, 0x08, 0x00, 0x92, 0x00, 0x01, 0x00, 0x00, 0x69, 0x2D, 0x1F }	// Get status
};

const uint8_t uart_response_baud_switched[12] = { 0x19, 0x81, 0x03, 0x07, 0x00, 0x94, 0x20, 0x00, 0x00, 0x00, 0x00, 0xA8 };
const uint8_t uart_mac_response_header[8] = { 0x19, 0x81, 0x03, 0x0F, 0x00, 0x94, 0x01, 0x08 };
const uint8_t uart_status_response_header[8] = { 0x19, 0x81, 0x03, 0x38, 0x00, 0x92, 0x00, 0x31 };	// Header for long responses

uart_joycon_t joycon_right;
uart_joycon_t joycon_left;
gpio_config_t pin_config; 

static void uart_joycon_write_next_command(uart_joycon_t * joycon) {
	uint8_t i;
	if (joycon->handshake_pos == 10) {
		uart_handshake_commands[joycon->handshake_pos][25] = host_mac_addr[5];
		uart_handshake_commands[joycon->handshake_pos][26] = host_mac_addr[4];
		uart_handshake_commands[joycon->handshake_pos][27] = host_mac_addr[3];
		uart_handshake_commands[joycon->handshake_pos][28] = host_mac_addr[2];
		uart_handshake_commands[joycon->handshake_pos][29] = host_mac_addr[1];
		uart_handshake_commands[joycon->handshake_pos][30] = host_mac_addr[0];
	}
	for (i = 1; i <= uart_handshake_commands[joycon->handshake_pos][0]; i++) joycon->uart_port->fifo.rw_byte = uart_handshake_commands[joycon->handshake_pos][i];
	if (joycon->handshake_pos < 14) joycon->handshake_pos++;
}
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
